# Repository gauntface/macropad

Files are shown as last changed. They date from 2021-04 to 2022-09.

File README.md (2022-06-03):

# Macropad

The PCB used the following libs:

- https://github.com/perigoso/keyswitch-kicad-library
- https://github.com/gauntface/kicad-libraries

## Arduino

1. Install the Arduino IDE
    1. Fedora should use flathub to avoid [this issue](https://github.com/arduino/Arduino/issues/11150)
        ```
        flatpak remote-add --if-not-exists flathub https://flathub.org/repo/flathub.flatpakrepo
        flatpak install flathub cc.arduino.arduinoide
        ```
1. Install the following libraries under `Tools > Manage Libraries`:
    - HID-Project
    - Adafruit GFX Library
    - Adafruit SSD1306
1. Install board in Arduino - [see Sparkfuns guide for pro micro](https://learn.sparkfun.com/tutorials/pro-micro--fio-v3-hookup-guide/installing-mac--linux)

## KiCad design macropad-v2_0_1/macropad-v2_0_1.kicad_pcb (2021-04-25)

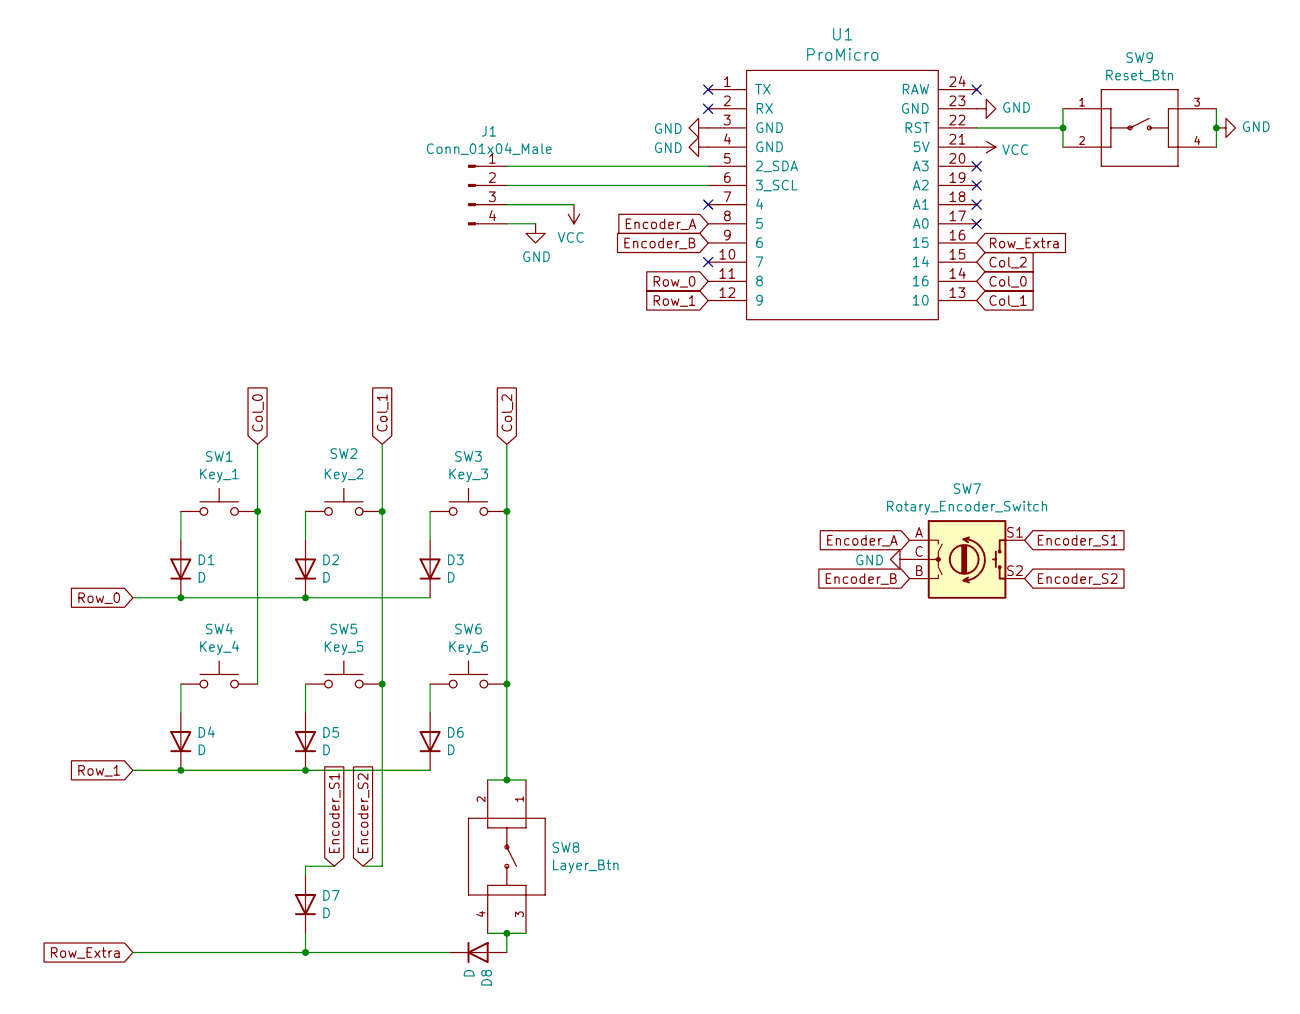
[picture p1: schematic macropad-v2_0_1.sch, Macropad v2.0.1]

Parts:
D1, D2, D3, D4, D5, D6, D7, D8: D; D_A-405_P7.62mm_Horizontal
J1: Conn_01x04_Male; Screen_38x12mm_JMD0_91_a
SW1: Key_1; SW_Hotswap_Kailh
SW2: Key_2; SW_Hotswap_Kailh
SW3: Key_3; SW_Hotswap_Kailh
SW4: Key_4; SW_Hotswap_Kailh
SW5: Key_5; SW_Hotswap_Kailh
SW6: Key_6; SW_Hotswap_Kailh
SW7: Rotary_Encoder_Switch; ACZ11BRXE
SW8: Layer_Btn; SW_1825910-6-4
SW9: Reset_Btn; SW_1825910-6-4
U1: ProMicro

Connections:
Col_0: SW1.2, SW4.2, U1.14 (16)
Col_1: SW2.2, SW5.2, SW7.S2, U1.13 (10)
Col_2: SW3.2, SW6.2, SW8.1, SW8.2, U1.15 (14)
Encoder_A: SW7.A, U1.8 (5)
Encoder_B: SW7.B, U1.9 (6)
Encoder_S1: D7.2 (A), SW7.S1
GND: J1.4, SW7.C, SW9.3, SW9.4, U1.3 (GND), U1.4 (GND), U1.23 (GND)
unnamed: D1.2 (A), SW1.1
unnamed: D2.2 (A), SW2.1
unnamed: D3.2 (A), SW3.1
unnamed: D4.2 (A), SW4.1
unnamed: D5.2 (A), SW5.1
unnamed: D6.2 (A), SW6.1
unnamed: D8.2 (A), SW8.3, SW8.4
unnamed: J1.1, U1.5 (2_SDA)
unnamed: J1.2, U1.6 (3_SCL)
unnamed: SW9.1, SW9.2, U1.22 (RST)
Row_0: D1.1 (K), D2.1 (K), D3.1 (K), U1.11 (8)
Row_1: D4.1 (K), D5.1 (K), D6.1 (K), U1.12 (9)
Row_Extra: D7.1 (K), D8.1 (K), U1.16 (15)
VCC: J1.3, U1.21 (5V)

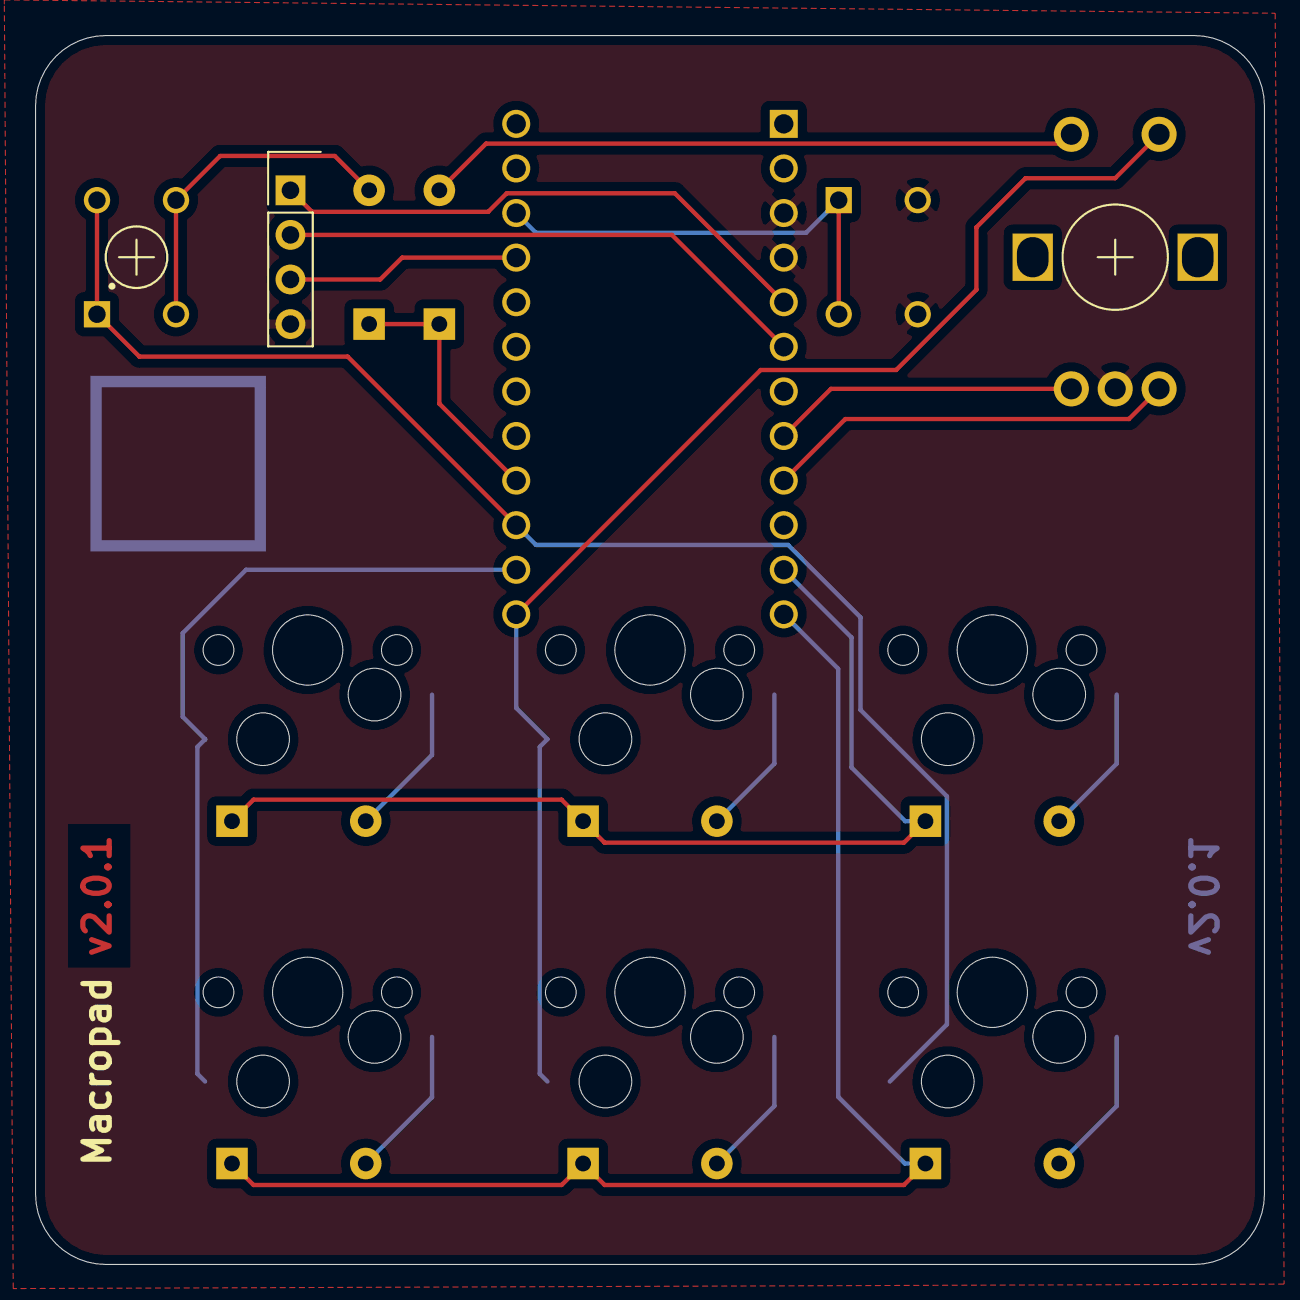
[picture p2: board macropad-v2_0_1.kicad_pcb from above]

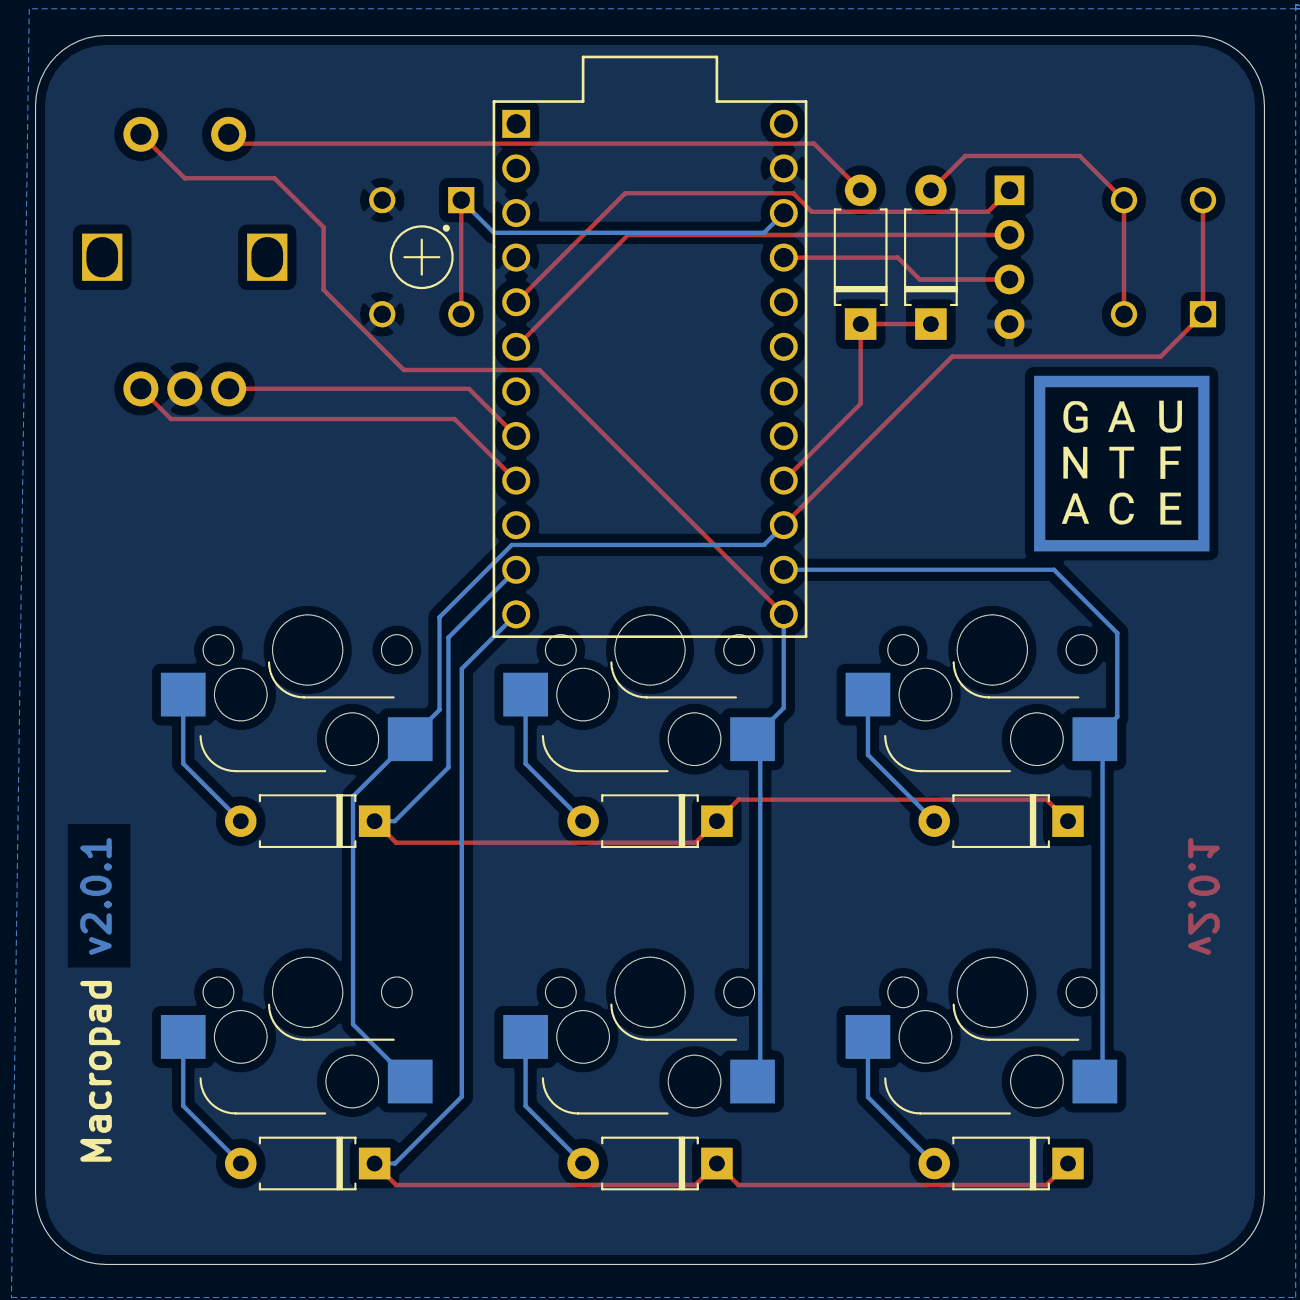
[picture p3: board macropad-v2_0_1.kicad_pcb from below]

Board: 2 copper layers, 70.0 x 70.0 mm, 20 parts (11 on the bottom side), 21 nets.

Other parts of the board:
Ref**: Val**; gauntface-logo

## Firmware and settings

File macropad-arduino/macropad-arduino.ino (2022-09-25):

#include <SPI.h>
#include <Wire.h>
#include "linuxlayer.cpp"
#include "maclayer.cpp"

String VERSION = "v2.0.0";

void setup()
{
  Serial.begin(9600);

  initDisplay();
  showSplashScreen();

  initKeys();
  initRotary();
  initLayers();
  initJiggler();
}

void loop()
{
  Layer* l = currentLayer();
  loopKeys(l);
  loopRotary(l);
  loopMouseJiggler();
}

void showSplashScreen(void) {
  int linesSize = 2;
  String lines[linesSize]={"Keypad", VERSION};

  renderText(linesSize, lines);
  delay(1000);
}

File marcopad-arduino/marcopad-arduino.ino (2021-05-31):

#include <SPI.h>
#include <Wire.h>
#include "linuxlayer.cpp"
#include "maclayer.cpp"

String VERSION = "v2.0.0";
boolean delayInit = false;

void setup()
{ 
  Serial.begin(9600);

  initDisplay();
  showSplashScreen();

  if (delayInit) {
    logCountdown();
  }
  
  initKeys();
  initRotary();
  initLayers();
}

void loop()
{
  Layer* l = currentLayer();
  loopKeys(l);
  loopRotary(l);
}

void showSplashScreen(void) {
  int linesSize = 2;
  String lines[linesSize]={"Keypad", VERSION};
  
  renderText(linesSize, lines);
  delay(1000);
}

void logCountdown() {
  Serial.println("0s");
  delay(2000);
  Serial.println("2s");
  delay(2000);
  Serial.println("4s");
  delay(2000);
  Serial.println("6s");
  delay(2000);
  Serial.println("8s");
  delay(2000);
  Serial.println("10s");
  delay(2000);
}

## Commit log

2021-03-22 Adding README
    [macropad-v2_0_0.kicad_pcb, macropad-v2_0_0.sch]
2021-04-11 Started coding up the keyboard matrix and finished v2
    [macropad-v2_0_0-B_Cu.gbl, macropad-v2_0_0-B_Mask.gbs, macropad-v2_0_0-B_Paste.gbp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]
2021-04-11 Adding update plot files
    [macropad-v2_0_0-B_Cu.gbl, macropad-v2_0_0-B_Mask.gbs, macropad-v2_0_0-B_Paste.gbp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]
2021-04-23 Adding working arduino code and second rev of schematic
    [macropad-v2_0_1.kicad_pcb, macropad-v2_0_1.sch]
2021-04-23 Adding paths to schematic
    [macropad-v2_0_1.kicad_pcb, macropad-v2_0_1.sch]
2021-04-25 Adding plots
    [macropad-v2_0_1-B_Cu.gbr, macropad-v2_0_1-B_Mask.gbr, macropad-v2_0_1-B_Paste.gbr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]
2021-05-31 Adding kicad and updating layer logic
